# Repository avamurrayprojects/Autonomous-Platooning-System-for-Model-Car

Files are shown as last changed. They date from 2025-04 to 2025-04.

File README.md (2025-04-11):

# Model Vehicle Platooning System.  
This repository contains the code for a model car platooning system developed as part of an academic project. The system enables a follower car to autonomously track and follow a lead car using computer vision and distance sensing. Key features include ArUco marker detection, PID-based speed and steering control, autonomous obstacle avoidance and searching behaviour when visual tracking is lost.

## System Overview  
The system is split across two Raspberry Pi units:  

**Pi 1: Image Processing**  
Responsible for capturing frames using a Raspberry Pi camera and detecting an ArUco marker placed on the rear of the lead car. It calculates the horizontal position of the marker in the frame and transmits this data via serial to the second Pi.  

**Pi 2: Control Pi**  
Handles all motion control functions including:  
- Reading distance measurements from the ultrasonic sensor.
- Running PID controllers for both steering and speed.
- Executing obstacle avoidance manoeuvres.
- Switching between oparational states.

This separating improves performance and allows the image processing to run at full frame rate without interfering with real-time control loops.

## Key Features  
**ArUco Marker Tracking** - Using OpenCV on the image Pi to track lead vehicle position.  
**PID Control** - Used for both smooth speed adjustments and accurate steering.  
**Obstacle Avoidance** - Detects and avoids any nearby obstacles with a defined manoeuvre.  
**State Machine Architecture** - Switches betweens *Not Platooning, Searching and Locked-On* modes.  
**Multi-Threaded Control** - INdependent threads for UART communication, steering, speed and state logic.  
**LED Indicators** - Show current state via LEDs.  

## Hardware Requirements  
- 2 x Raspberry Pi (testd with Raspberry Pi Model 4 b)
- Raspberry Pi Camera Module v2
- HC-SR04 ULtrasonic Sensor
- L298N Motor Driver
- DC Motor
- Standard Servo
- Battery Pack
- ArUco Marker printed and mounted to lead car
- *Optional: 3 x LED, 4 x push button, toggle switch*

## Licence
This project is intended for academic and educational use. Please cite appropriately if used in your own work.

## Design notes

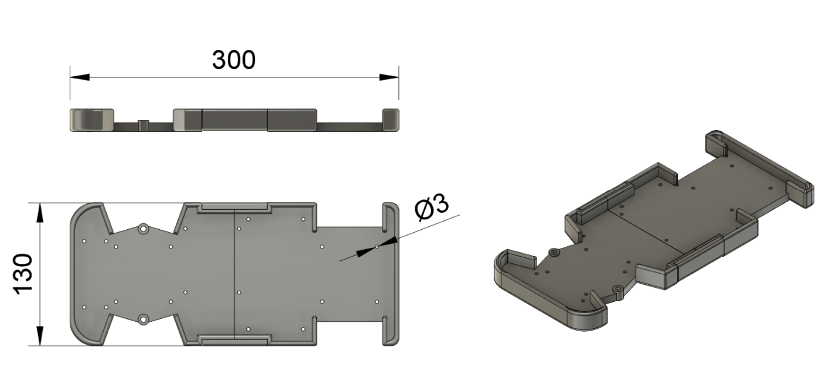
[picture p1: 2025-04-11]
hardware/images/base-chassis.png

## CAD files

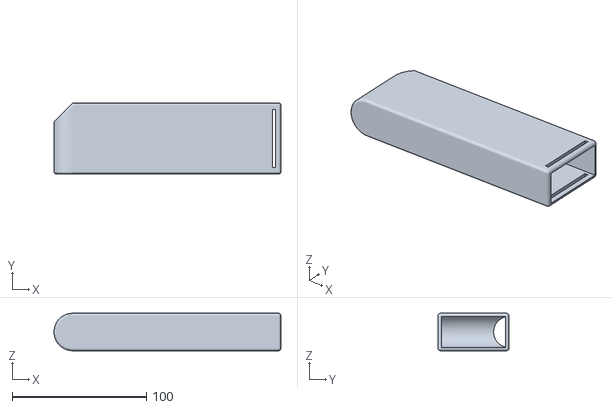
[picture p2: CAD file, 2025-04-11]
hardware/STL/battery-case/battery-case.stl
169.0 x 53.0 x 28.0

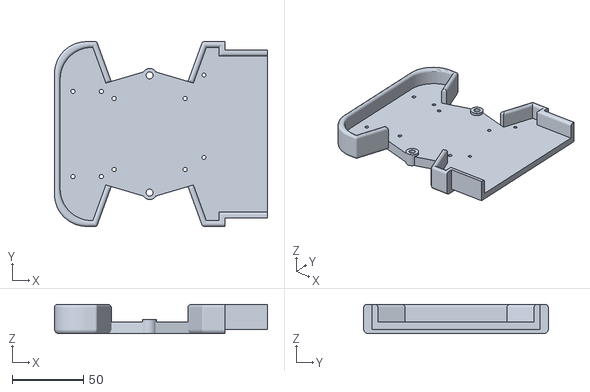
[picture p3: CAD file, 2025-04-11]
hardware/STL/chassis/chassis-front.stl
150.0 x 130.0 x 20.5

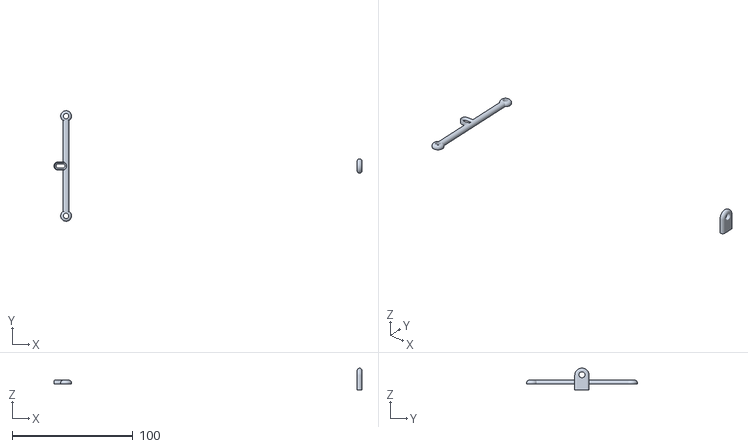
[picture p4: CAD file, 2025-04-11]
hardware/STL/mounts/rear-motor-mount-rear.stl
254.8 x 91.5 x 18.0

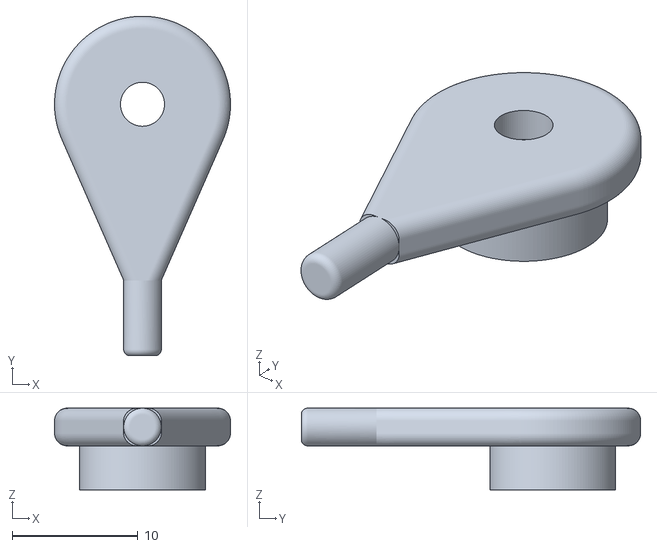
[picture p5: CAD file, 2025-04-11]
hardware/STL/steering/steering-arm.stl
14.0 x 27.0 x 6.50

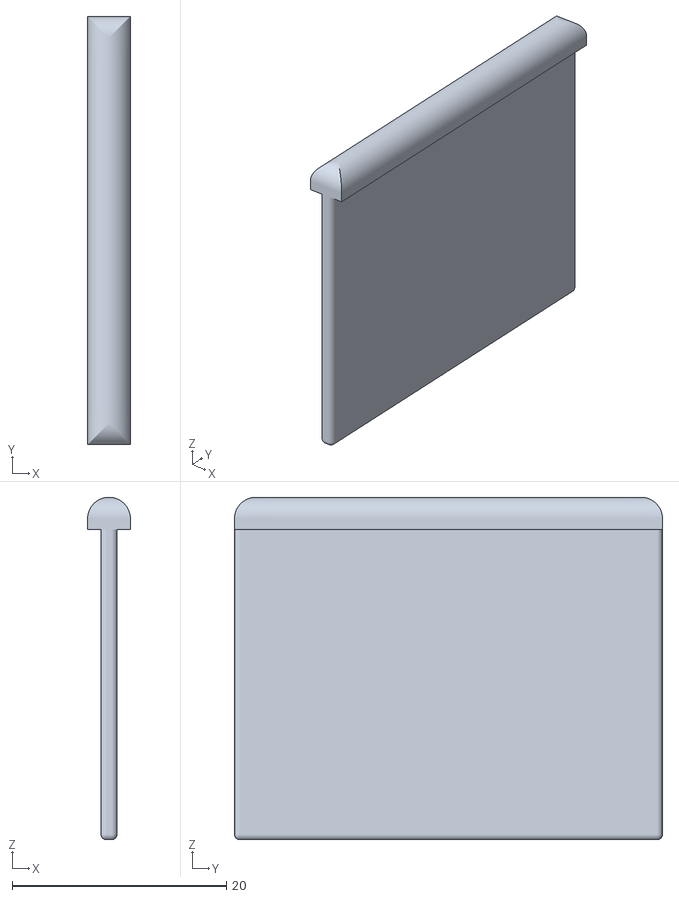
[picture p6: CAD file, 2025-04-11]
hardware/STL/battery-case/battery-case-end.stl
4.00 x 40.0 x 32.0

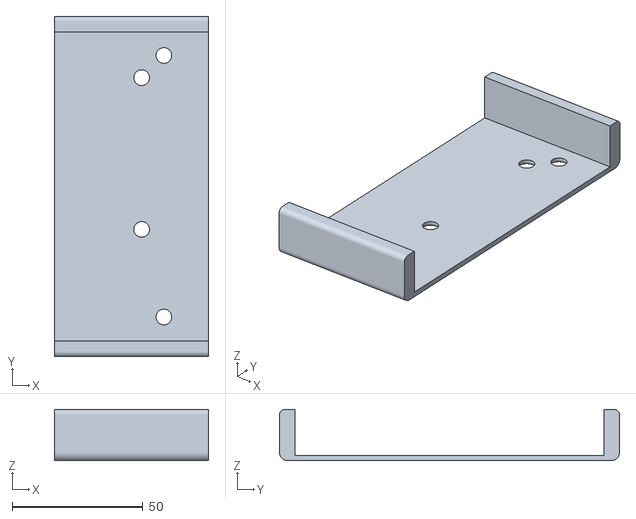
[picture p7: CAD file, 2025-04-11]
hardware/STL/chassis/chassis-connector.stl
59.0 x 130.0 x 19.5

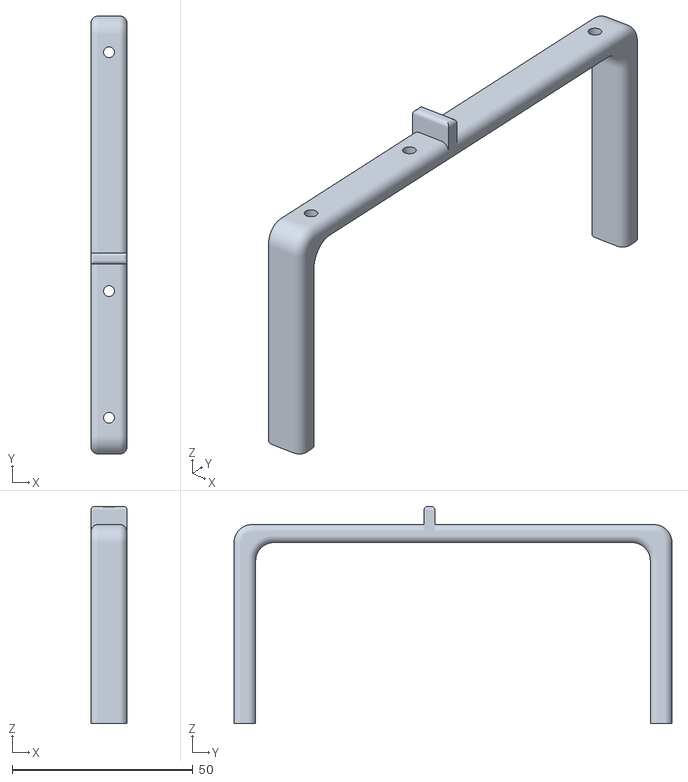
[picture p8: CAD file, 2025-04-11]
hardware/STL/mounts/front-battery-frame.stl
10.0 x 121.0 x 60.0

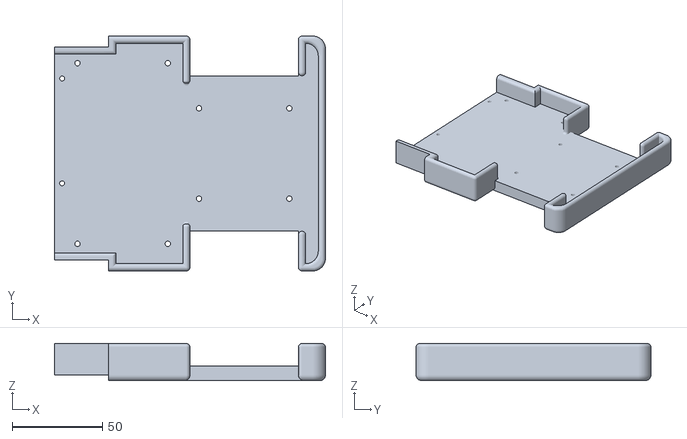
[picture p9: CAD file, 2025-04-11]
hardware/STL/chassis/chassis-rear.stl
150.0 x 130.0 x 20.5

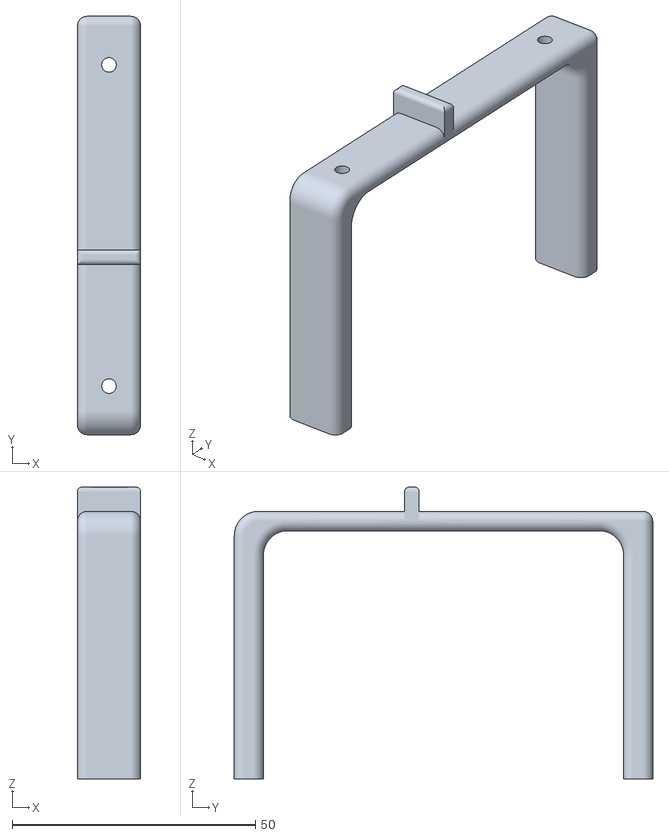
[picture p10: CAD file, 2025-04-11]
hardware/STL/mounts/rear-battery-frame.stl
13.0 x 86.0 x 60.0

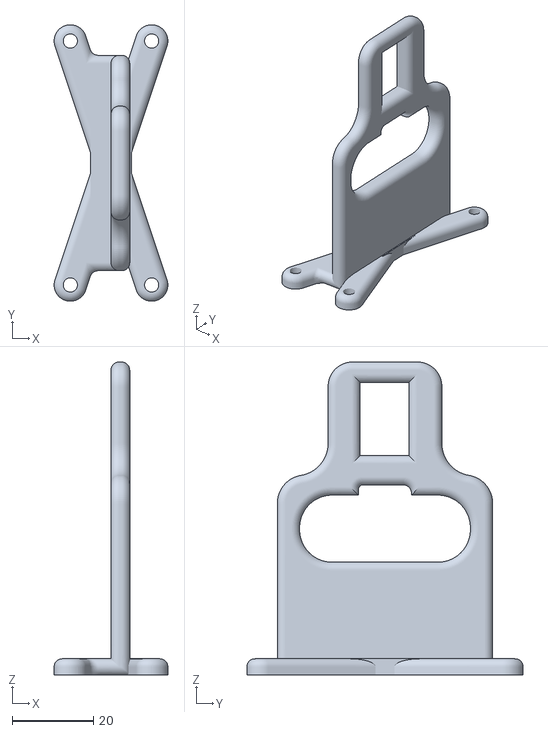
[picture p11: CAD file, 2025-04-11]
hardware/STL/mounts/camera-ultrasonic-mount.stl
28.0 x 68.0 x 77.0

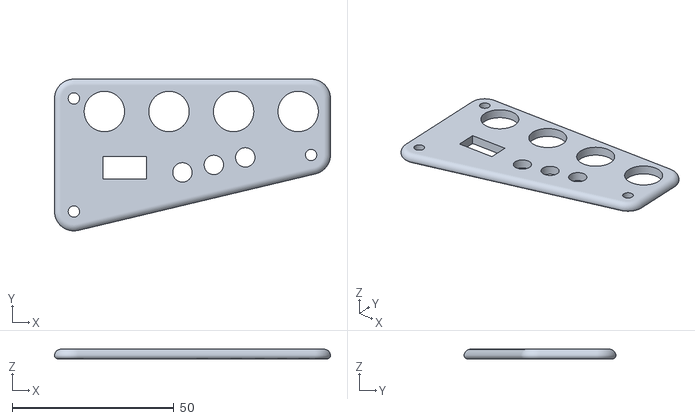
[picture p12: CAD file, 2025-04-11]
hardware/STL/mounts/button-panel.stl
85.4 x 47.0 x 3.00

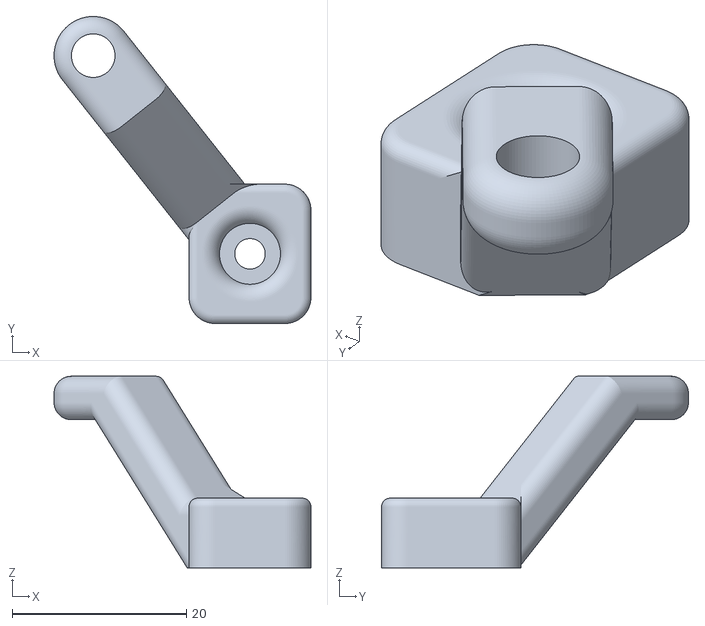
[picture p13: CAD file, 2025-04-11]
hardware/STL/mounts/right-kingpin-cap.stl
29.5 x 35.2 x 22.0

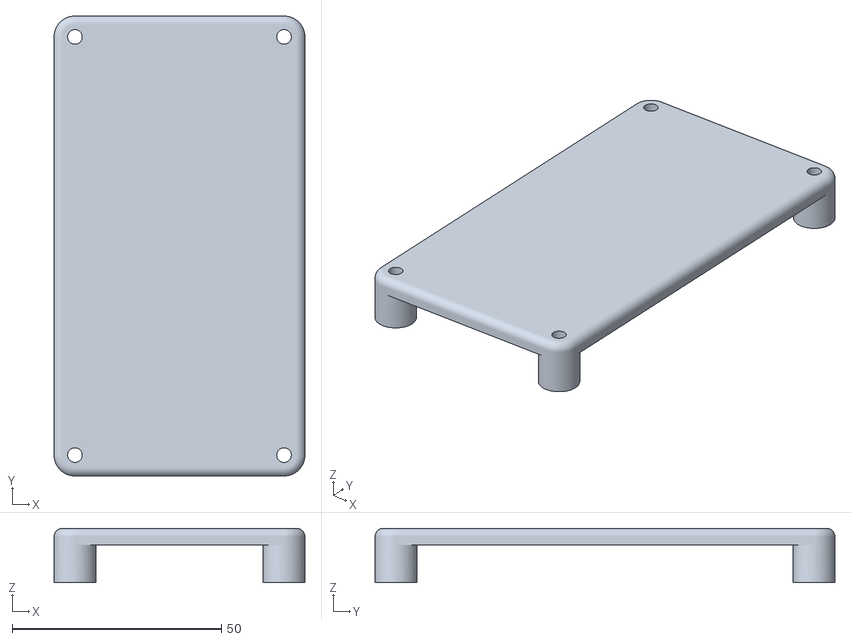
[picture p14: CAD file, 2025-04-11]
hardware/STL/mounts/board-mount.stl
60.0 x 110.0 x 13.0

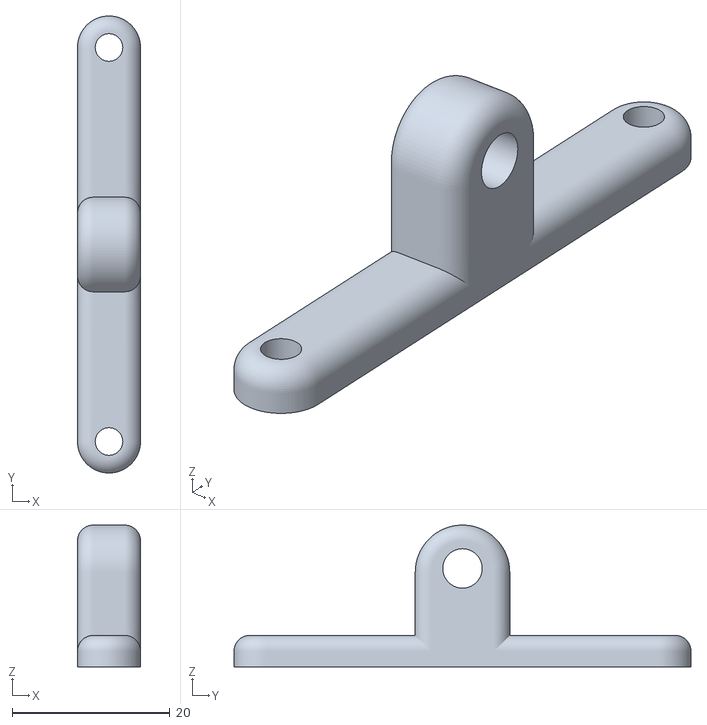
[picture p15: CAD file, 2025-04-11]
hardware/STL/mounts/rear-motor-mount-front.stl
8.00 x 58.0 x 18.0

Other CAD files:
hardware/STL/mounts/left-kingpin-cap.stl
hardware/STL/mounts/servo-mount.stl

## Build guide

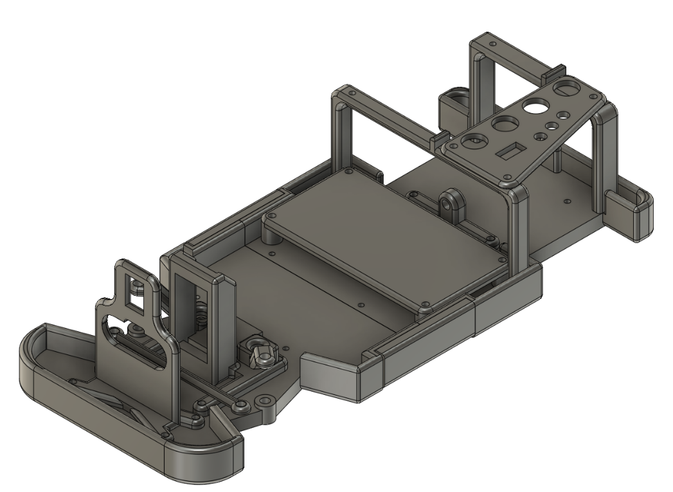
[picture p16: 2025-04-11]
hardware/images/full-assembly.png

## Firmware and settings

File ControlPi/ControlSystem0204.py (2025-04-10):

import threading
import time
import serial  
import pigpio
from collections import deque

    
                             
class PIDController:
   
       
    def __init__(self, kp, ki, kd, setpoint=160.0, sample_time=0.01):
        self.kp = kp #proportional
        self.ki = ki #Integral
        self.kd = kd #Derivative
        self.setpoint = setpoint #target value
        self.sample_time = sample_time #interval of computations in seconds
       
        self.last_marker_time =time.time()#timestamp for when marker was last seen
       

        # internal variables
        self._last_error = 0.0
        self._integral = 0.0
        self._last_time = time.time()

    #compute is used to compute output
    def compute(self, current_value):
       
        now = time.time()
        dt = now - self._last_time
        if dt < self.sample_time:
            # Not enough time has passed to compute
            return None

        error = self.setpoint - current_value
        self._integral += error * dt
        derivative = 0.0
        if dt > 0:
            derivative = (error - self._last_error) / dt

        # PID output
        output = (self.kp * error) + (self.ki * self._integral) + (self.kd * derivative)

        # Update for next round
        self._last_error = error
        self._last_time = now

        return output


#follower class
                             
class PlatoonFollower:
    #states are used by state machine to determine the mode of operation
    STATE_NOT_PLATOONING = "NOT_PLATOONING"
    STATE_SEARCHING = "SEARCHING"
    STATE_LOCKED_ON = "LOCKED_ON"
   
    def __init__(self,
                 uart_port='/dev/serial0', 
                 baud_rate=115200,
                 steering_pin=18,
                 trigger_pin=23,
                 echo_pin=24,
                 motor_pwm_pin=25,
                 motor_in1_pin=27,
                 motor_in2_pin=22,
                 pigpio_instance = None,
                 toggle_button_pin = 6,
                 GREEN_LED_PIN = 19,
                 YELLOW_LED_PIN = 26,
                 RED_LED_PIN= 13,
                 locked_on_time = None
                ):  
   

        # Configuration
        self.uart_port = uart_port #Serial port for communication   
        self.baud_rate = baud_rate #baud rate of data
        self.steering_pin = steering_pin #pin for servo
        self.trigger_pin = trigger_pin # pin for ultrasonic sensor trigger
        self.echo_pin = echo_pin #pin for ultrasonic echo
        self.motor_pwm_pin = motor_pwm_pin
        self.motor_in1_pin = motor_in1_pin
        self.motor_in2_pin = motor_in2_pin
        self.use_constant_speed = False
        self.constant_speed=30
        self.use_constant_steering = False
        self.override_steering = False
        self.searching_distance_start = None
        
        self.center_threshold = 70



        #following are for switching states
        self.last_button_state = 1 #starts unpressed and pulled high
        self.last_toggle_time = 0
        self.toggle_debounce = 0.25
        self.toggle_button_pin = toggle_button_pin

        self.servo_pulse =1500
        self.servo_dir = 1

        self.platooning_pin = self.toggle_button_pin

        self.state = self.STATE_NOT_PLATOONING #setting state to not platooning automatically
        self.sweeping = False

        self.marker_seen_buffer = deque(maxlen=10)  # buffer of last 10 frames

        self.steering_pid = PIDController(kp=1.0, ki=0.0, kd=0.0, setpoint=160.0)
       
        

        # Shared state variables
        self.x_position = 0.0          # from serial
        self.distance_measured = 999.0 # from HC-SR04
        self.running = True            # for thread control
       
        self.previous_distance = None
        
        #PID setup for speed control
        self.distance_setpoint = 45.0
        self.speed_pid = PIDController(kp=0.1, ki= 0.0, kd = 0.11, setpoint=self.distance_setpoint, sample_time = 0.1)
        self.previous_speed = 0 
       
        #Pigpiod instance
        self.pi = pigpio_instance or pigpio.pi()
        self._own_pigpio = pigpio_instance is None #stop only if we created it
        if not self.pi.connected:
            raise RuntimeError("Could not connect to pigpio daemon")

        # Initialize hardware
        self.setup_gpio()
        self._setup_port()
        self.median_buffer = deque(maxlen=6)
        self.median_usage_count = 0
        self.invalid_count = 0
        self.last_valid_distance = None
        
        #leds
        self.RED_LED =RED_LED_PIN
        self.YELLOW_LED =YELLOW_LED_PIN
        self.GREEN_LED =GREEN_LED_PIN
        
        self.pi.set_mode(self.RED_LED, pigpio.OUTPUT)
        self.pi.set_mode(self.YELLOW_LED, pigpio.OUTPUT)
        self.pi.set_mode(self.GREEN_LED, pigpio.OUTPUT)
        self.pi.write(self.RED_LED, 1)                     

         # Threads
        self.uart_thread = threading.Thread(target=self.uart_listener, daemon=True)
        self.steering_thread = threading.Thread(target=self.steering_control, daemon=True)
        self.speed_thread = threading.Thread(target=self.speed_control, daemon=True)
        self.state_thread = threading.Thread(target=self.state_machine_loop, daemon = True)


    # Hardware Setup                      
    def setup_gpio(self):
        #setting input and output pins
        self.pi = pigpio.pi()
        if not self.pi.connected:
            raise RuntimeError("Could not connect to pigpio daemon")
           
        # Set modes for servo and motor pins using pigpio
        self.pi.set_mode(self.steering_pin, pigpio.OUTPUT)
        self.pi.set_mode(self.motor_pwm_pin, pigpio.OUTPUT)
        self.pi.set_mode(self.motor_in1_pin, pigpio.OUTPUT)
        self.pi.set_mode(self.motor_in2_pin, pigpio.OUTPUT)
        self.pi.set_mode(self.trigger_pin, pigpio.OUTPUT)
        self.pi.set_mode(self.echo_pin, pigpio.INPUT)

        # platooning toggling
        self.pi.set_mode(self.platooning_pin, pigpio.INPUT)
        self.pi.set_mode(self.toggle_button_pin, pigpio.INPUT)
        self.pi.set_pull_up_down(self.toggle_button_pin, pigpio.PUD_UP)


        # For motor PWM
        self.pi.set_PWM_frequency(self.motor_pwm_pin, 100)
        
    def update_leds(self,state):
        self.pi.write(self.RED_LED, 0)
        self.pi.write(self.YELLOW_LED, 0)
        self.pi.write(self.GREEN_LED, 0)
    
        
        if state == self.STATE_NOT_PLATOONING:
                self.pi.write(self.RED_LED, 1)
        elif state == self.STATE_SEARCHING:
                self.pi.write(self.YELLOW_LED, 1)
        elif state == self.STATE_LOCKED_ON:
                self.pi.write(self.GREEN_LED, 1)


    def _setup_port(self):
    
        self.serial_conn = serial.serial_for_url(self.uart_port,
                                                 baudrate=self.baud_rate,
                                                 timeout=1)

    #UART listener                     
    def uart_listener(self):
        #print("uart listener called")
        #continously reading in data
        while self.running:
            try:
                line = self.serial_conn.readline().decode('utf-8').strip()
                #print("raw  line: {line}" )
                if line:
                    #print(f"UART REceived: {line}") #add back in after testing
                    # Expecting a string that represents a float for X position
                    try:
                        if line in ["NO_MARKER"]:
                            self.marker_visible = False
                        else:
                            self.x_position = float(line)
                            self.marker_visible = True
                            self.last_marker_time = time.time()

                        self.marker_seen_buffer.append(self.marker_visible)
                    except ValueError:
                         self.marker_visible = False

                    #print("Serial line: " + str(line))
            except Exception as e:
                                                   
                #print(f"[UART Listener] Exception: {e}")
                #sleep briefly before trying again
                time.sleep(0.1)
    def get_valid_median(self, max_age_sec=3.0):
        # Special case: if just entered LOCKED_ON, force fallback to 40
        if self.state == self.STATE_LOCKED_ON and self.locked_on_time is not None:
            if time.time() - self.locked_on_time < 1.0:
                return 40.0
            
        now = time.time()
        valid = [val for val, ts in self.median_buffer if now -ts <= max_age_sec]
        
        if not valid:
            return None
        
        valid.sort()
        mid = len(valid)//2
        if len(valid) % 2 == 0:
            return (valid[mid - 1] + valid[mid]) / 2
        else:
            return valid[mid]
        
    def handle_obstacle_during_searching(self, repeat_count=0):
        MAX_REPEATS = 3

        print("[SEARCHING] Obstacle too close for 2s — starting avoidance maneuver")
        self.override_steering = True
        self.pi.set_servo_pulsewidth(self.steering_pin, 1500)
        time.sleep(0.1)  # allow steering thread to pause

        # Reverse Phase
        print("[SEARCHING] Reversing...")
        self.pi.write(self.motor_in1_pin, 0)
        self.pi.write(self.motor_in2_pin, 1)
        reverse_duty = int(25 * 255 / 100)
        self.pi.set_PWM_dutycycle(self.motor_pwm_pin, reverse_duty)

        reverse_start = time.time()
        while time.time() - reverse_start < 1:
            if not self.running or self.state != self.STATE_SEARCHING:
                break
            time.sleep(0.1)

        #Stop after reverse
        self.pi.set_PWM_dutycycle(self.motor_pwm_pin, 0)
        self.pi.write(self.motor_in1_pin, 1)
        self.pi.write(self.motor_in2_pin, 1)
        time.sleep(0.1)
        self.pi.write(self.motor_in1_pin, 0)
        self.pi.write(self.motor_in2_pin, 0)

        #Check Before Forward 
        check_distance = self.distance_measured
        if check_distance < 30: 
            print(f"[SEARCHING] Aborting forward — obstacle still close ({check_distance:.2f} cm)")
            self.override_steering = False
            return

        #Forward Turn Phase
        print("[SEARCHING] Forward + steer right...")
        self.pi.set_servo_pulsewidth(self.steering_pin, 1700)  # steer left
        forward_duty = int(20 * 255 / 100)
        self.pi.set_PWM_dutycycle(self.motor_pwm_pin, forward_duty)
        
        self.pi.write(self.motor_in1_pin, 1)
        self.pi.write(self.motor_in2_pin, 0)
        print(f"Forward duty: {forward_duty}, IN1=1, IN2=0")

        forward_start = time.time()
        while time.time() - forward_start < 1.5:
            if not self.running or self.state != self.STATE_SEARCHING:
                break

            current_distance = self.distance_measured
            if current_distance < 30:
                print(f"[SEARCHING] Obstacle during forward: {current_distance:.2f} cm — aborting")
                break

            time.sleep(0.1)

        # Stop motor and steering
        self.pi.set_PWM_dutycycle(self.motor_pwm_pin, 0)
        self.pi.write(self.motor_in1_pin, 1)
        self.pi.write(self.motor_in2_pin, 1)
        time.sleep(0.1)
        self.pi.write(self.motor_in1_pin, 0)
        self.pi.write(self.motor_in2_pin, 0)
        self.pi.set_servo_pulsewidth(self.steering_pin, 1500)

        print("[SEARCHING] Maneuver complete — resuming normal operation")
        self.override_steering = False

        #Post-check: Repeat if still blocked
        post_distance = self.distance_measured
        print(f"[SEARCHING] Post-maneuver distance: {post_distance:.2f} cm")

        if post_distance < 30 and repeat_count < MAX_REPEATS and self.state == self.STATE_SEARCHING:
            print("[SEARCHING] Obstacle still close — repeating avoidance maneuver")
            self.handle_obstacle_during_searching(repeat_count + 1)
            



    #steering control
                                         
    #gets ran in its own seperate thread                    
    def steering_control(self):
        #1100us (left), 1500us (center), 1900us (right)
        center_pw = 1500  # Center pulse width
        min_pw = 1100     # Minimum pulse width
        max_pw = 1900     # Maximum pulse width
        max_pixel_error = 160  # Maximum pixel error (0 to 320 image, with center at 160)
        max_correction_us =200  # Maximum correction in microseconds (2% of 20ms period)
        #rate limter additions
        current_pw = center_pw
        max_servo_step = 20
       
        while self.running:
            try:
                if self.state == self.STATE_NOT_PLATOONING or self.override_steering:
                    time.sleep(0.1)
                    continue
                        
                       
                elif self.state == self.STATE_SEARCHING:
                    distance_measured = self.distance_measured
                    current_time = time.time()

                    # Trigger avoidance if object is too close
                    if not self.sweeping:
                        self.sweeping = True
                        self.servo_sweep()
                        self.sweeping = False
                    continue

                       
                elif self.state == self.STATE_LOCKED_ON:
                    if self.use_constant_steering:
                        self.pi.set_servo_pulsewidth(self.steering_pin, center_pw)
                        time.sleep(self.steering_pid.sample_time)
                        continue
                    
                    #test
                    if self.use_constant_steering:
                        self.pi.set_servo_pulsewidth(self.steering_pin, center_pw)
                        time.sleep(self.steering_pid.sample_time)
                        continue

                    # Only compute correction if marker is visible
                    if self.marker_visible and self.x_position is not None:
                        pid_output = self.steering_pid.compute(self.x_position)
                        if pid_output is not None:
                            correction = pid_output
                            scaled_correction = (correction / max_pixel_error) * max_correction_us
                            pulsewidth = center_pw + scaled_correction

                            # Clamp target pulse within min/max bounds
                            target_pw = max(min_pw, min(max_pw, pulsewidth))

                            # Initialize current_pw if not already
                            if not hasattr(self, 'current_pw'):
                                self.current_pw = center_pw

                            # Rate limiting
                            if target_pw > self.current_pw + max_servo_step:
                                self.current_pw += max_servo_step
                            elif target_pw < self.current_pw - max_servo_step:
                                self.current_pw -= max_servo_step
                            else:
                                self.current_pw = target_pw

                            self.last_steering_pw = self.current_pw
                            self.pi.set_servo_pulsewidth(self.steering_pin, self.current_pw)
                    else:
                        # Marker not visible — hold last known position
                        if hasattr(self, 'last_steering_pw'):
                            self.pi.set_servo_pulsewidth(self.steering_pin, self.last_steering_pw)

                    time.sleep(self.steering_pid.sample_time)
            except Exception as e:
                print(f"[Steering Control] Exception: {e}")
                time.sleep(0.1)

   

                                 
    def _measure_distance(self):
        #using sensor to measure distance
        # 10us pulse
        self.pi.write(self.trigger_pin, 1)
        time.sleep(0.00001)
        self.pi.write(self.trigger_pin, 0)

        timeout = 0.1
        start_time = time.time()

         # Wait for the echo to go high
        while self.pi.read(self.echo_pin) == 0:
            if time.time() - start_time > timeout or not self.running:
                print("Timeout waiting for echo start")
                return 0
            time.sleep(0.001)  # brief sleep to allow flag check

        echo_start = time.time()

        # Wait for the echo to go low
        while self.pi.read(self.echo_pin) == 1:
            if time.time() - echo_start > timeout or not self.running:
                print("Timeout waiting for echo end")
                return 0
            time.sleep(0.001)  # brief sleep to allow flag check

        echo_end = time.time()

        elapsed = echo_end - echo_start
        #34300 is speed of sound
        distance = (elapsed * 34300) / 2
        print("Measured distance: " + str(distance))
        return distance


    #speed control using ultrasonic sensor - ran on speed control thread
    def speed_control(self):
        #uses sensor to measure distance and adjusts speed accordingly
        while self.running:
            try:
                    if self.state == self.STATE_NOT_PLATOONING:
                        self.pi.set_PWM_dutycycle(self.motor_pwm_pin, 0)
                        time.sleep(0.2)
                        continue
                    
                    distance_measured = self._measure_distance()
                    self.distance_measured = distance_measured
                           
                    if self.state == self.STATE_SEARCHING:
                        self.pi.write(self.motor_in1_pin, 1)
                        self.pi.write(self.motor_in2_pin, 1)
                        
                        current_time = time.time()
                        self.pi.set_PWM_dutycycle(self.motor_pwm_pin, 30)
                        

                        if distance_measured < 30:
                            self.pi.write(self.motor_in1_pin, 1)
                            self.pi.write(self.motor_in2_pin, 1)
                            time.sleep(0.1)
                            self.pi.write(self.motor_in1_pin, 0)
                            self.pi.write(self.motor_in2_pin, 0)
                            
                            if self.searching_distance_start is None:
                                self.searching_distance_start = current_time
                            elif current_time - self.searching_distance_start >= 2:
                                self.handle_obstacle_during_searching()
                                self.searching_distance_start = None  # Reset after manoeuvre
                        elif distance_measured > 35:
                            self.pi.write(self.motor_in1_pin, 1)
                            self.pi.write(self.motor_in2_pin, 0)
                            self.searching_distance_start = None
                        
                        else: 
                            self.pi.write(self.motor_in1_pin, 0)
                            self.pi.write(self.motor_in2_pin, 0)
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

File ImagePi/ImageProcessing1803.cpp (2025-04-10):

#include <opencv2/opencv.hpp>
#include <opencv2/aruco.hpp>
#include <opencv2/video/tracking.hpp> // Kalman and other tracking algorithms
#include <iostream>
#include <deque>
#include <fcntl.h>  // file control operations
#include <unistd.h> // POSIX os API (r/w)
#include <sys/ioctl.h> // ioctl function
#include <termios.h>

// Configuration structure holds program parameters
struct Config {
    // Desired processing resolution (downscaled image size)
    int frameWidth = 320;
    int frameHeight = 240;
    double frameRate = 30.0;
   
    // ArUco marker dictionary
    int arucoDictId = cv::aruco::DICT_4X4_250;
   
    // Kalman filter parameters
    int kalmanStateSize = 4; // x, y, vx, vy
    int kalmanMeasSize  = 2; // measuring only x and y
    int kalmanContrSize = 0;
    unsigned int kalmanType = CV_32F;
    float processNoisePos = 1e-2;
    float processNoiseVel = 5.0f;
    float measNoisePos    = 1e-1;
    float errorCovPos     = 1.0f;
    float errorCovVel     = 1.0f;
   
    // Buffer size for smoothing detections
    int bufferSize = 1;
   
    // Image processing parameters
    cv::Size gaussianKernelSize = cv::Size(5, 5);
    double gaussianSigmaX = 0;
    int adaptiveThreshBlockSize = 11;
    double adaptiveThreshC = 2.0;
   
    // Virtual serial port parameters
    std::string uartDevice = "/dev/serial0";
    int baudRate = 115200;
    
    int noMarkerThreshold = 4; //amount of consecutive frames without detection
};

// Check if GUI mode is enabled via the "--gui" argument
bool is_gui_mode(int argc, char** argv) {
    for (int i = 1; i < argc; ++i) {
        if (std::string(argv[i]) == "--gui") {
            return true;
        }
    }
    return false;
}

int main(int argc, char** argv) {
    Config config;
    bool gui_enabled = is_gui_mode(argc, argv);

    // Open UART device (virtual serial port)
    int serial_fd = open(config.uartDevice.c_str(), O_RDWR | O_NOCTTY | O_NDELAY);
    if (serial_fd < 0) {
        std::cerr << "Error opening UART device: " << config.uartDevice << std::endl;
        return -1;
    }
   
    // Configure the serial port
    struct termios tty;
    if (tcgetattr(serial_fd, &tty) != 0) {
        std::cerr << "Error from tcgetattr\n";
        close(serial_fd);
        return -1;
    }
    cfsetispeed(&tty, B115200);
    cfsetospeed(&tty, B115200);
    tty.c_cflag &= ~PARENB;  // no parity
    tty.c_cflag &= ~CSTOPB;  // one stop bit
    tty.c_cflag &= ~CSIZE;
    tty.c_cflag |= CS8;      // 8 data bits
    tty.c_cflag &= ~CRTSCTS; // disable hardware flow control
    tty.c_cflag |= CREAD | CLOCAL; // enable receiver, local mode
    tty.c_lflag &= ~(ICANON | ECHO | ECHOE | ISIG); // raw input mode
    tty.c_oflag &= ~OPOST;   // raw output
    tty.c_iflag &= ~(IXON | IXOFF | IXANY); // disable software flow control
    if (tcsetattr(serial_fd, TCSANOW, &tty) != 0) {
        std::cerr << "Error from tcsetattr\n";
        close(serial_fd);
        return -1;
    }

    // Capture Setup
    // Use an open-ended pipeline that doesn't force a resolution.
    // This lets the camera output its native full resolution.
    std::string pipeline = "libcamerasrc ! videoconvert ! appsink";

    // Open camera using the pipeline string
    cv::VideoCapture cap(pipeline, cv::CAP_GSTREAMER);
    if (!cap.isOpened()) {
        std::cerr << "Could not open camera using pipeline:\n" << pipeline << std::endl;
        close(serial_fd);
        return -1;
    }
   
    cv::Mat fullFrame, frame, gray;
    double ticks = 0;
    double dt = 1.0 / config.frameRate;
   
    // Initialize ArUco detection and Kalman filter
    cv::Ptr<cv::aruco::Dictionary> dictionary =
        cv::aruco::getPredefinedDictionary(config.arucoDictId);

    cv::KalmanFilter kf(config.kalmanStateSize,
                        config.kalmanMeasSize,
                        config.kalmanContrSize,
                        config.kalmanType);
    cv::setIdentity(kf.transitionMatrix);
    kf.measurementMatrix = cv::Mat::zeros(config.kalmanMeasSize,
                                          config.kalmanStateSize,
                                          config.kalmanType);
    kf.measurementMatrix.at<float>(0, 0) = 1.0f;
    kf.measurementMatrix.at<float>(1, 1) = 1.0f;

    kf.processNoiseCov = cv::Mat::zeros(config.kalmanStateSize,
                                        config.kalmanStateSize,
                                        config.kalmanType);
    kf.processNoiseCov.at<float>(0, 0) = config.processNoisePos;
    kf.processNoiseCov.at<float>(1, 1) = config.processNoisePos;
    kf.processNoiseCov.at<float>(2, 2) = config.processNoiseVel;
    kf.processNoiseCov.at<float>(3, 3) = config.processNoiseVel;

    kf.measurementNoiseCov = cv::Mat::zeros(config.kalmanMeasSize,
                                            config.kalmanMeasSize,
                                            config.kalmanType);
    kf.measurementNoiseCov.at<float>(0, 0) = config.measNoisePos;
    kf.measurementNoiseCov.at<float>(1, 1) = config.measNoisePos;

    cv::Mat state(config.kalmanStateSize, 1, config.kalmanType, cv::Scalar(0));
    cv::Mat meas(config.kalmanMeasSize, 1, config.kalmanType, cv::Scalar(0));

    std::deque<cv::Point2f> buffer;
    bool found = false;
    
    int noMarkerFrames = 0;
    bool markerRecentlyVisible = true;

    // Main loop
    while (true) {
        // Capture the full resolution frame from the camera
        if (!cap.read(fullFrame) || fullFrame.empty()) {
            std::cerr << "Error reading frame\n";
            break;
        }
       
        // Downscale the full resolution image to the processing resolution.
        // This way, you preserve the full field of view.
        cv::resize(fullFrame, frame, cv::Size(config.frameWidth, config.frameHeight));
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
